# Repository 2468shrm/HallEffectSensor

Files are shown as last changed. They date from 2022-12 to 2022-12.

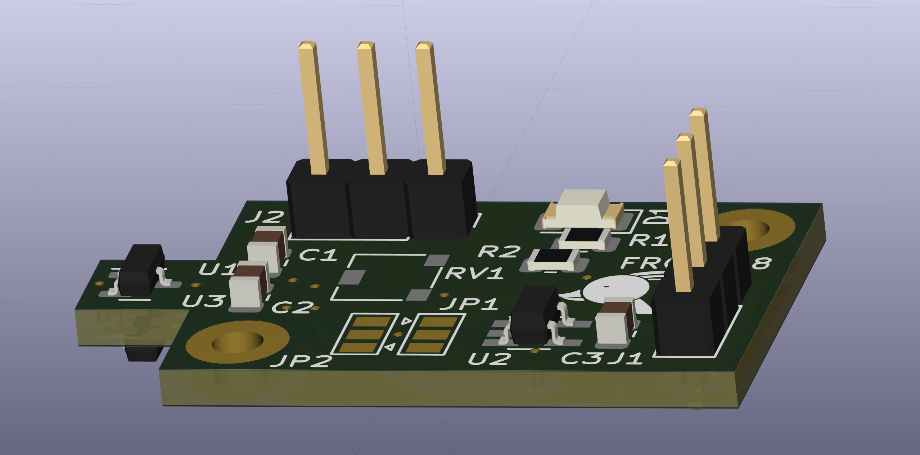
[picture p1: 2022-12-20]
IMAGES/HallEffectSensor_iso.png

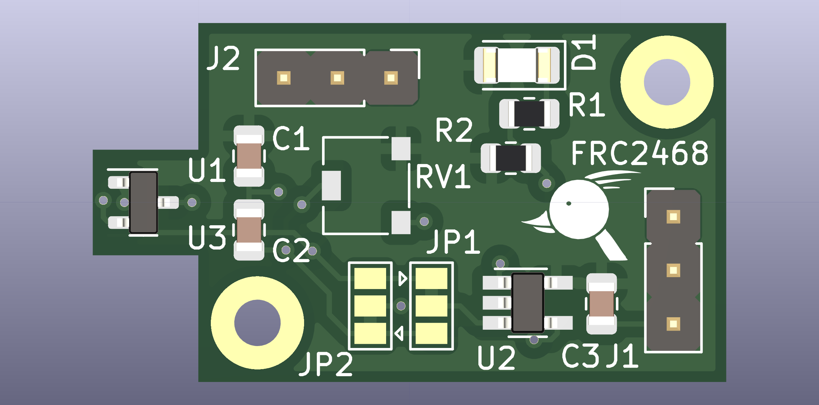
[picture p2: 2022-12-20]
IMAGES/HallEffectSensor.png

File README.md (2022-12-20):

# HallEffectSensor

This is a simple sensor for FRC mechanisms based on the Honeywell SM351LT.
The intended uses include contactless extension/rotation limit sensing.
I've tried many times to get the team to use one on turrets or elevators
and I hope that creating one for the team might encourage their use.

The datasheet for the sensor is [here](https://www.mouser.com/datasheet/2/187/HWSC_S_A0012827053_1-3073404.pdf).

The operating voltage of this circuit is 3.3V. The connector to a connecting
single-board computer is a 3-pin signal/power/ground 0.1 inch header.  It is
3.3V since the sensor operates at 3.3V and there was no intention of including
a 5V-to-3.3V regulator to minimize costs.

Since limit sensing is a digital operation (you're at the limit or not)
the circuit includes a voltage divider to set a sensitivity/reference level
and comparator to digitize the sensing. It also includes a LED to indicate
the output of the sensor.

There are two 3-pin 0.1" header footprints.
- One for the connection to a DIO on a feather board
- One that is in parallel to the output of the sensor, so that the sensor may
be depopulated an another 3.3V sensor is connected externally, OR, it makes a
good probe point

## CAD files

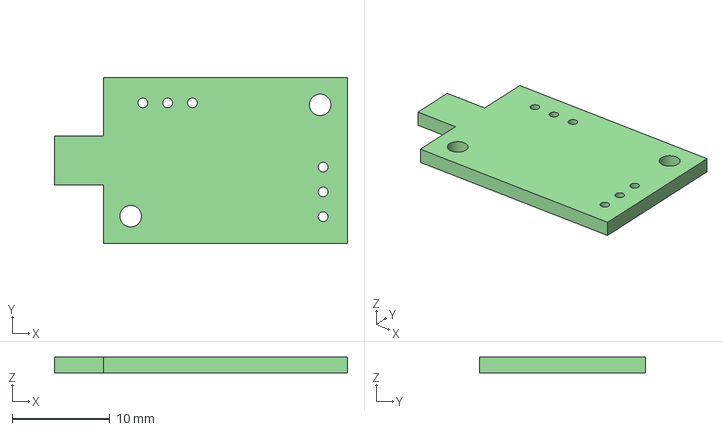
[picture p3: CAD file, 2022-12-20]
STEP/HallEffectSensor.step
30.0 x 17.0 x 1.60 mm

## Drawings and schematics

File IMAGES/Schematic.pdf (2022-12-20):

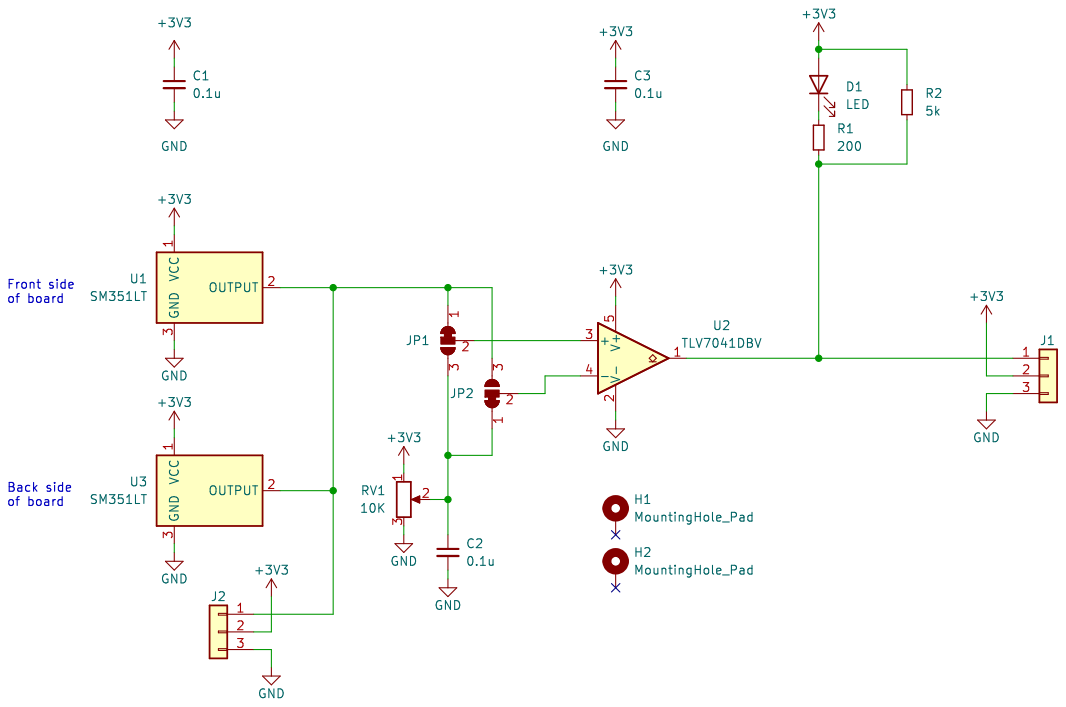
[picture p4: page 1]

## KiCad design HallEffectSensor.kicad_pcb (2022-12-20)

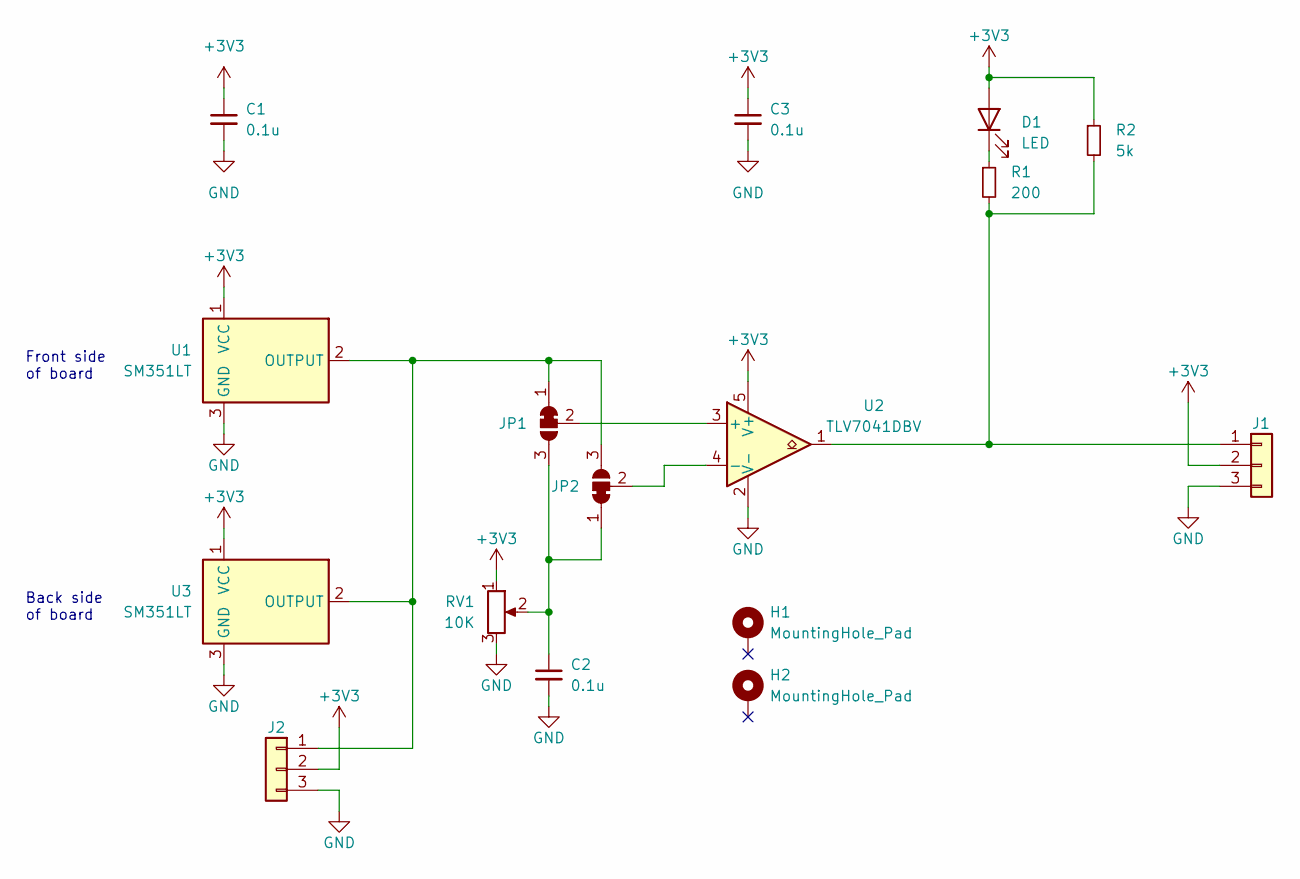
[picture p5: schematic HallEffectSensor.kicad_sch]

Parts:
C1, C2, C3: 0.1u; C_0805_2012Metric
D1: LED; LED_1206_3216Metric
H1, H2: MountingHole_Pad; MountingHole_2.2mm_M2_Pad
J1, J2: Conn_01x03; PinHeader_1x03_P2.54mm_Vertical
JP1, JP2: SolderJumper_3_Bridged12; SolderJumper-3_P1.3mm_Bridged12_Pad1.0x1.5mm
R1: 200; R_0805_2012Metric
R2: 5k; R_0805_2012Metric
RV1: 10K; PVG3A
U1, U3: SM351LT; SOT-23
U2: TLV7041DBV; SOT-23-5_HandSoldering

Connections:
+3V3: C1.1, C3.1, D1.2 (A), J1.2, J2.2, R2.1, RV1.1, U1.1 (VCC), U2.5 (V+), U3.1 (VCC)
GND: C1.2, C2.2, C3.2, J1.3, J2.3, RV1.3, U1.3 (GND), U2.2 (V-), U3.3 (GND)
unnamed: C2.1, JP1.3 (B), JP2.1 (A), RV1.2
unnamed: D1.1 (K), R1.1
unnamed: J1.1, R1.2, R2.2, U2.1
unnamed: J2.1, JP1.1 (A), JP2.3 (B), U1.2 (OUTPUT), U3.2 (OUTPUT)
unnamed: JP1.2 (C), U2.3 (+)
unnamed: JP2.2 (C), U2.4 (-)

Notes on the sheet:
Front side of board
Back side of board

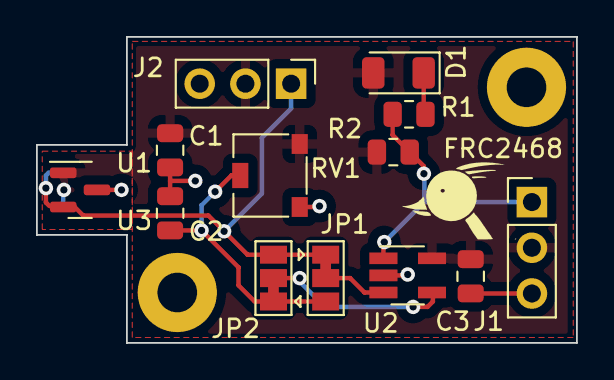
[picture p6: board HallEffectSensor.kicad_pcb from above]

Board: 2 copper layers, 30.0 x 17.0 mm, 16 parts (1 on the bottom side), 8 nets.
